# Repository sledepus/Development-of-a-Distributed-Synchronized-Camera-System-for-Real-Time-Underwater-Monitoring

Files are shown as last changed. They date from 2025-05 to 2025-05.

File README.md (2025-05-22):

# Development of a Distributed Synchronized Camera System for Real-Time Underwater Monitoring
<div style="text-align: center;">
    
</div>

This is the Git repository of the bachelor thesis "Development of a Distributed Synchronized Camera System for Real-Time Underwater Monitoring", carried out at the University of Agder by students from the Mechatronics and Electronics engineering programs.

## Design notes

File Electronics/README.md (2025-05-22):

# KiCAD projects for power board and sensor board
BOM for boards are found in their respective folder. PCBs were ordered from JLCPCB, with the power board requiring a specific stackup which can be found in "Specifications for JLCPCB.txt". The sensor board could be ordered with the normal stackup.

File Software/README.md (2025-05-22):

# Overview of dependencies needed
## Sensors:
smbus2 (Python package to interface with I2C via Python)
flask (Python package to run a lightweight HTTP server)
flask_cors (Extension package to flask)

Line 5 in start_monitoring.sh needs to point to correct Python virtual environment

## Sync:
### On Nvidia Jetson:
Jetson.GPIO (Python package to interface with GPIO on Jetson via Python)
Chrony (Lightweight NTP client / server)

Line 5 in start_sync.sh needs to point to correct Python virtual environment

### On Host PC:
aiohttp (Asynchronus HTTP client / server for Python)
Chrony (Lightweight NTP client / server)

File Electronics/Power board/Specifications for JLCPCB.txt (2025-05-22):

4 layer board
1.6mm PCB thickness
ENIG surface finish
Epoxy Filled & Capped vias
JLC04161H-7628 stackup

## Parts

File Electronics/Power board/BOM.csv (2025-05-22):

Reference | Value |  | Footprint | Qty | DNP | Cost | Link | Total cost: | 616.35
C1 | 1nF |  | Capacitor_SMD:C_1808_4520Metric_Pad1.72x2.30mm_HandSolder | 1 |  | 6.33 | https://no.mouser.com/ProductDetail/TDK/C4520X7R3D102K130KA?qs=NRhsANhppD%2FmDDEB06mgKg%3D%3D
C2 | 0.047uF |  | Capacitor_SMD:C_1206_3216Metric_Pad1.33x1.80mm_HandSolder | 1 |  | 5.06 | https://no.mouser.com/ProductDetail/TDK/C3216X7R2A474K160AA?qs=NRhsANhppD%2F0AFSm3iY27A%3D%3D
C3 | 0.047uF |  | Capacitor_SMD:C_1206_3216Metric_Pad1.33x1.80mm_HandSolder | 1 |  | 5.06 | https://no.mouser.com/ProductDetail/TDK/C3216X7R2A474K160AA?qs=NRhsANhppD%2F0AFSm3iY27A%3D%3D
C4 | 0.047uF |  | Capacitor_SMD:C_1206_3216Metric_Pad1.33x1.80mm_HandSolder | 1 |  | 5.06 | https://no.mouser.com/ProductDetail/TDK/C3216X7R2A474K160AA?qs=NRhsANhppD%2F0AFSm3iY27A%3D%3D
C5 | 220uF |  | local symbols:CAPPRD500W65D1250H2700 | 1 |  | 18.63 | https://no.mouser.com/ProductDetail/Panasonic/EEU-FS2A221B?qs=w%2Fv1CP2dgqqAbg7G%252BWfZEw%3D%3D
C6 | 2.2uF |  | Capacitor_SMD:C_1206_3216Metric | 1 |  | 5.06 | https://no.mouser.com/ProductDetail/Samsung-Electro-Mechanics/CL31B225KCHSNNE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
C7 | 2.2uF |  | Capacitor_SMD:C_1206_3216Metric | 1 |  | 5.06 | https://no.mouser.com/ProductDetail/Samsung-Electro-Mechanics/CL31B225KCHSNNE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
C8 | 2.2uF |  | Capacitor_SMD:C_1206_3216Metric | 1 |  | 5.06 | https://no.mouser.com/ProductDetail/Samsung-Electro-Mechanics/CL31B225KCHSNNE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
C9 | 0.1uF |  | Capacitor_SMD:C_0603_1608Metric_Pad1.08x0.95mm_HandSolder | 1 |  | 1.15 | https://no.mouser.com/ProductDetail/Samsung-Electro-Mechanics/CL10B104KC8NNNC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
C10 | 2.2uF |  | Capacitor_SMD:C_1206_3216Metric | 1 |  | 5.06 | https://no.mouser.com/ProductDetail/Samsung-Electro-Mechanics/CL31B225KCHSNNE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
C11 | 1uF |  | Capacitor_SMD:C_0603_1608Metric_Pad1.08x0.95mm_HandSolder | 1 |  | 3.11 | https://no.mouser.com/ProductDetail/TDK/C1608X7R2A105K080AC?qs=efUn273yAhc5BfjaNflQJg%3D%3D
C12 | 2.2uF |  | Capacitor_SMD:C_1206_3216Metric | 1 |  | 5.06 | https://no.mouser.com/ProductDetail/Samsung-Electro-Mechanics/CL31B225KCHSNNE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
C13 | 2.2uF |  | Capacitor_SMD:C_1206_3216Metric | 1 |  | 5.06 | https://no.mouser.com/ProductDetail/Samsung-Electro-Mechanics/CL31B225KCHSNNE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
C14 | 2.2uF |  | Capacitor_SMD:C_1206_3216Metric | 1 |  | 5.06 | https://no.mouser.com/ProductDetail/Samsung-Electro-Mechanics/CL31B225KCHSNNE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
C15 | 22nF |  | Capacitor_SMD:C_0603_1608Metric_Pad1.08x0.95mm_HandSolder | 1 |  | 1.15 | https://no.mouser.com/ProductDetail/TDK/C1608X7R1H223K080AA?qs=NRhsANhppD%2FQDsEEQkak2g%3D%3D
C16 | 0.18uF |  | Capacitor_SMD:C_0603_1608Metric_Pad1.08x0.95mm_HandSolder | 1 |  | 2.07 | https://no.mouser.com/ProductDetail/Murata-Electronics/GRM188R71E184JA88D?qs=4W3PNmGdEWESKFPR14%2FptQ%3D%3D
C17 | 20SVPA10M |  | local symbols:16SVF82M | 1 |  | 10.12 | https://no.mouser.com/ProductDetail/Panasonic/20SVPA10M?qs=kmv%2FWw32SUMFO%252BR%252BBoc1uQ%3D%3D
C18 | 20SVPA10M |  | local symbols:16SVF82M | 1 |  | 10.12 | https://no.mouser.com/ProductDetail/Panasonic/20SVPA10M?qs=kmv%2FWw32SUMFO%252BR%252BBoc1uQ%3D%3D
C19 | 4.7uF |  | Capacitor_SMD:C_1206_3216Metric_Pad1.33x1.80mm_HandSolder | 1 |  | 3.34 | https://no.mouser.com/ProductDetail/TDK/C3216X7R1E475K160AC?qs=NRhsANhppD%252B1ueqJBZSgVQ%3D%3D
C20 | C |  | Capacitor_SMD:C_0603_1608Metric_Pad1.08x0.95mm_HandSolder | 1 |  | DNP | DNP
C21 | 0.1uF |  | Capacitor_SMD:C_1206_3216Metric_Pad1.33x1.80mm_HandSolder | 1 |  | 2.76 | https://no.mouser.com/ProductDetail/TDK/C3216X7R2A104M160AA?qs=NRhsANhppD9n088ccj0Rog%3D%3D
D1 | SMAJ60A |  | Diode_SMD:D_SMA | 1 |  | 3.11 | https://no.mouser.com/ProductDetail/Littelfuse/SMAJ60A?qs=JJML70Qc14uXU90ZhvFagg%3D%3D
J1 | 2250504-1 |  | local symbols:22505041 | 1 |  | 103.33 | https://no.mouser.com/ProductDetail/TRP-Connector-Bel/2250504-1?qs=BZBei1rCqCBflgaPUpS30g%3D%3D
J2 | SS-60000-008 |  | local symbols:BEL_SS-60000-008 | 1 |  | 42.71 | https://no.mouser.com/ProductDetail/Stewart-Connector-Bel/SS-60000-008?qs=FESYatJ8odLtCYolbGascQ%3D%3D
J3 | Conn_02x01 |  | Connector_PinHeader_2.54mm:PinHeader_2x01_P2.54mm_Vertical | 1 |  | DNP | DNP
J4 | Conn_02x01 |  | Connector_PinHeader_2.54mm:PinHeader_2x01_P2.54mm_Vertical | 1 |  | DNP | DNP
J5 | 1935187 |  | local symbols:1935187 | 1 |  | 11.16 | https://no.mouser.com/ProductDetail/Phoenix-Contact/1935187?qs=W3wJikR1%252BS5tIYApIw6HoQ%3D%3D
L1 | 10uH |  | local symbols:WE-XHMI_1090 | 1 |  | 63.77 | https://no.mouser.com/ProductDetail/Wurth-Elektronik/74439369100?qs=rQFj71Wb1eU71nvM%252BwSuXg%3D%3D
Q1 | PSMN040-100MSE |  | Package_TO_SOT_SMD:LFPAK33 | 1 |  | 12.95 | https://no.mouser.com/ProductDetail/Nexperia/PSMN040-100MSEX?qs=5XOdhvmYM0P4Ftmbr2cr4A%3D%3D
Q2 | PSMN040-100MSE |  | Package_TO_SOT_SMD:LFPAK33 | 1 |  | 12.95 | https://no.mouser.com/ProductDetail/Nexperia/PSMN040-100MSEX?qs=5XOdhvmYM0P4Ftmbr2cr4A%3D%3D
Q3 | PSMN040-100MSE |  | Package_TO_SOT_SMD:LFPAK33 | 1 |  | 12.95 | https://no.mouser.com/ProductDetail/Nexperia/PSMN040-100MSEX?qs=5XOdhvmYM0P4Ftmbr2cr4A%3D%3D
Q4 | PSMN040-100MSE |  | Package_TO_SOT_SMD:LFPAK33 | 1 |  | 12.95 | https://no.mouser.com/ProductDetail/Nexperia/PSMN040-100MSEX?qs=5XOdhvmYM0P4Ftmbr2cr4A%3D%3D
Q5 | PSMN040-100MSE |  | Package_TO_SOT_SMD:LFPAK33 | 1 |  | 12.95 | https://no.mouser.com/ProductDetail/Nexperia/PSMN040-100MSEX?qs=5XOdhvmYM0P4Ftmbr2cr4A%3D%3D
Q6 | PSMN040-100MSE |  | Package_TO_SOT_SMD:LFPAK33 | 1 |  | 12.95 | https://no.mouser.com/ProductDetail/Nexperia/PSMN040-100MSEX?qs=5XOdhvmYM0P4Ftmbr2cr4A%3D%3D
Q7 | PSMN040-100MSE |  | Package_TO_SOT_SMD:LFPAK33 | 1 |  | 12.95 | https://no.mouser.com/ProductDetail/Nexperia/PSMN040-100MSEX?qs=5XOdhvmYM0P4Ftmbr2cr4A%3D%3D
Q8 | PSMN040-100MSE |  | Package_TO_SOT_SMD:LFPAK33 | 1 |  | 12.95 | https://no.mouser.com/ProductDetail/Nexperia/PSMN040-100MSEX?qs=5XOdhvmYM0P4Ftmbr2cr4A%3D%3D
Q9 | PSMN040-100MSE |  | Package_TO_SOT_SMD:LFPAK33 | 1 |  | 12.95 | https://no.mouser.com/ProductDetail/Nexperia/PSMN040-100MSEX?qs=5XOdhvmYM0P4Ftmbr2cr4A%3D%3D
R1 | 75 |  | Resistor_SMD:R_1206_3216Metric_Pad1.30x1.75mm_HandSolder | 1 |  | 1.15 | https://no.mouser.com/ProductDetail/YAGEO/RT1206DRE0775RL?qs=sGAEpiMZZMvdGkrng054t98Xz4DA4UW4Ozg3T4IT1xw%3D
R2 | 75 |  | Resistor_SMD:R_1206_3216Metric_Pad1.30x1.75mm_HandSolder | 1 |  | 1.15 | https://no.mouser.com/ProductDetail/YAGEO/RT1206DRE0775RL?qs=sGAEpiMZZMvdGkrng054t98Xz4DA4UW4Ozg3T4IT1xw%3D
R3 | 75 |  | Resistor_SMD:R_1206_3216Metric_Pad1.30x1.75mm_HandSolder | 1 |  | 1.15 | https://no.mouser.com/ProductDetail/YAGEO/RT1206DRE0775RL?qs=sGAEpiMZZMvdGkrng054t98Xz4DA4UW4Ozg3T4IT1xw%3D
R4 | 75 |  | Resistor_SMD:R_1206_3216Metric_Pad1.30x1.75mm_HandSolder | 1 |  | 1.15 | https://no.mouser.com/ProductDetail/YAGEO/RT1206DRE0775RL?qs=sGAEpiMZZMvdGkrng054t98Xz4DA4UW4Ozg3T4IT1xw%3D
R5 | 49.9 |  | Resistor_SMD:R_0603_1608Metric_Pad0.98x0.95mm_HandSolder | 1 |  | 1.5 | https://no.mouser.com/ProductDetail/Vishay-Dale/RCS060349R9FKEA
R6 | 118 |  | Resistor_SMD:R_0603_1608Metric_Pad0.98x0.95mm_HandSolder | 1 |  | 1.22 | https://no.mouser.com/ProductDetail/KOA-Speer/RK73H1JTTD1180F?qs=beCmh%2FXShNfPnDZ%2FNfW%252BWA%3D%3D
R7 | 0 |  | Resistor_SMD:R_1206_3216Metric_Pad1.30x1.75mm_HandSolder | 1 |  | 1.15 | https://no.mouser.com/ProductDetail/Vishay-Dale/CRCW12060000Z0EC
R8 | 3.3k |  | Resistor_SMD:R_0603_1608Metric_Pad0.98x0.95mm_HandSolder | 1 |  | 1.15 | https://no.mouser.com/ProductDetail/YAGEO/AC0603JR-073K3L?qs=sGAEpiMZZMvdGkrng054t7zOzNqIRvGcrCxgTvkGHR4%3D
R9 | 100k |  | Resistor_SMD:R_0603_1608Metric_Pad0.98x0.95mm_HandSolder | 1 |  | 1.15 | https://no.mouser.com/ProductDetail/YAGEO/AT0603FRE07100KL
R10 | 2.21k |  | Resistor_SMD:R_0603_1608Metric_Pad0.98x0.95mm_HandSolder | 1 |  | 1.15 | https://no.mouser.com/ProductDetail/Panasonic/ERJ-3EKF2211V?qs=sGAEpiMZZMvdGkrng054t8ugkoYZivkgwRdtRslwd94%3D
R11 | 2.2 |  | Resistor_SMD:R_0603_1608Metric_Pad0.98x0.95mm_HandSolder | 1 |  | 2.42 | https://no.mouser.com/ProductDetail/Vishay-Dale/RCS06032R20FKEA
R12 | 348 |  | Resistor_SMD:R_0603_1608Metric_Pad0.98x0.95mm_HandSolder | 1 |  | 2.42 | https://no.mouser.com/ProductDetail/Panasonic/ERJ-H3EF3480V
R13 | 8.2k |  | Resistor_SMD:R_0603_1608Metric_Pad0.98x0.95mm_HandSolder | 1 |  | 1.61 | https://no.mouser.com/ProductDetail/Vishay-Dale/RCS06038K20FKEA
R14 | 100k |  | Resistor_SMD:R_0603_1608Metric_Pad0.98x0.95mm_HandSolder | 1 |  | 1.15 | https://no.mouser.com/ProductDetail/YAGEO/AT0603FRE07100KL
R15 | 2.2 |  | Resistor_SMD:R_0603_1608Metric_Pad0.98x0.95mm_HandSolder | 1 |  | 2.42 | https://no.mouser.com/ProductDetail/Vishay-Dale/RCS06032R20FKEA
R16 | R |  | Resistor_SMD:R_0603_1608Metric_Pad0.98x0.95mm_HandSolder | 1 |  | DNP | DNP
U1 | LT4321IUF |  | Package_DFN_QFN:QFN-16-1EP_4x4mm_P0.65mm_EP2.15x2.15mm | 1 |  | 46.39 | https://www.digikey.no/no/products/detail/analog-devices-inc/LT4321IUF-PBF/4431235
U2 | LT4293IMS-PBF |  | footprints:05-08-1661_ADI | 1 |  | 58.08 | https://no.mouser.com/ProductDetail/Analog-Devices/LT4293IMSPBF?qs=PzGy0jfpSMs1qV0%2FehZ1Mw%3D%3D
U3 | MIC28516T-E/PHA |  | footprints:VQFN32_6X6_3EP_PHA_MCH | 1 |  | 39.93 | https://no.mouser.com/ProductDetail/Microchip-Technology/MIC28516T-E-PHA?qs=y6ZabgHbY%252By6jC%2FkhCS6gQ%3D%3D
 | Komponenter til 1 kort | 616.35
 | Bestilling av 5 kort (uten stencil) | 832.44
 | eller
 | Bestilling av 5 kort (med stencil) | 1172.45
 | Totalt pr kort (uten stencil) | 782.838
 | Totalt pr kort (med stencil) | 850.84

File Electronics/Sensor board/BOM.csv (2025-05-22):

Reference | Value | Datasheet | Footprint | Qty | Part number
C1, C3 | 100nF | ~ | Capacitor_SMD:C_1206_3216Metric | 1 | VJ1206Y104KXQCW1BC
C2 | 1uF | ~ | Capacitor_SMD:C_1206_3216Metric | 2 | 1206ZC105KAT2A
C3 | 10uF | ~ | Capacitor_SMD:C_1206_3216Metric | 1 | CL31B106KPHNNNE
IC1 | ADXL345BCCZ | http://www.st.com/resource/en/datasheet/lsm6ds3tr-c.pdf | KiCad:LSM6DS3USTR | 1 | ADXL345BCCZ
J1,J2 | 4328 |  | Library:ADAFRUIT_4328 | 2 | 485-4328
R1,R2,R3,R4 | 2.2k | ~ | Resistor_SMD:R_1206_3216Metric | 4 | CRCW12062K20FKEAC
U1 | SHTC3 | https://www.sensirion.com/fileadmin/user_upload/customers/sensirion/Dokumente/0_Datasheets/Humidity/Sensirion_Humidity_Sensors_SHTC3_Datasheet.pdf | Sensor_Humidity:Sensirion_DFN-4-1EP_2x2mm_P1mm_EP0.7x1.6mm | 1 | SHTC3

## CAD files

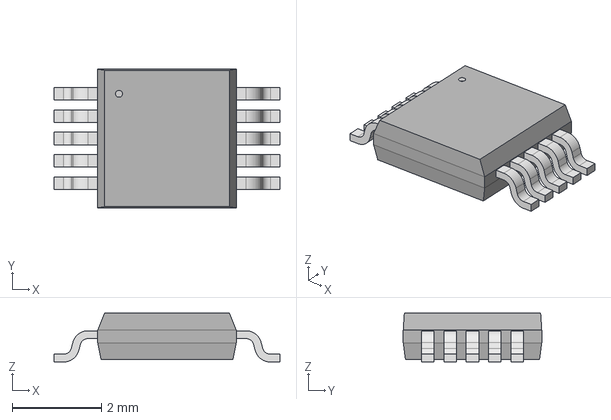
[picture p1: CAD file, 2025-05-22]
Electronics/Power board/local symbols/KiCADv6/05-08-1661_ADI.step
5.05 x 3.10 x 1.09 mm

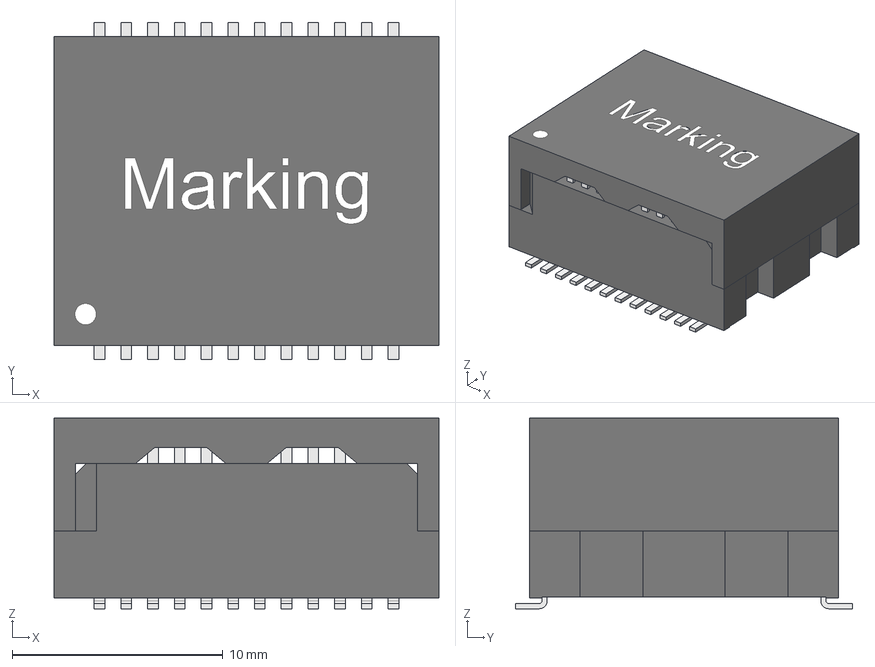
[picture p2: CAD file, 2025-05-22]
Electronics/Power board/local symbols/WE-LAN_7490220122.step
18.3 x 16.0 x 9.05 mm
Housing
Cover
Pins x 24

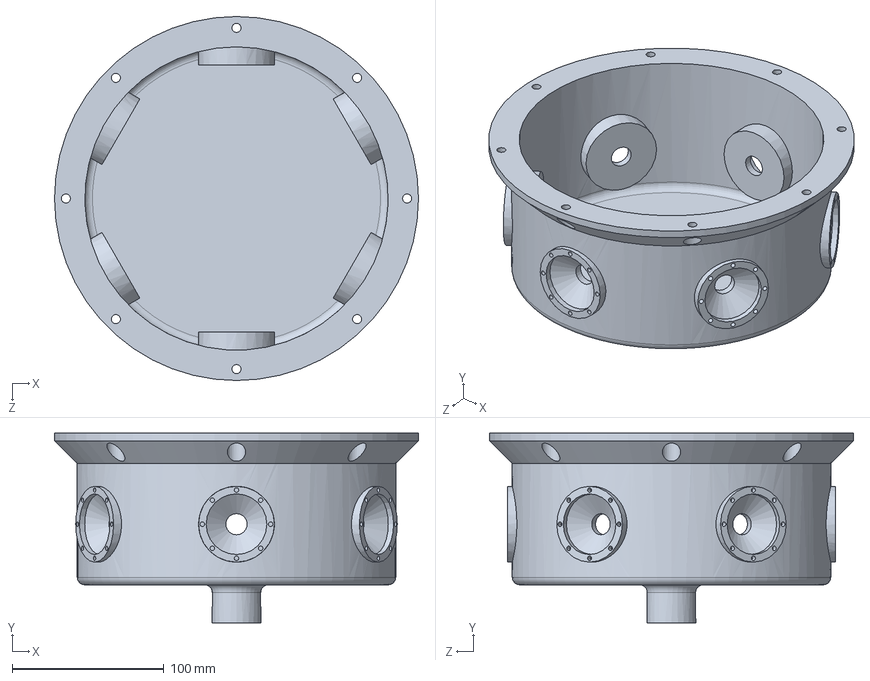
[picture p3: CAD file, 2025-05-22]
Mechanical Assembly - CAD/Final updated design/Top_node.SLDPRT
240.0 x 125.0 x 240.0 mm

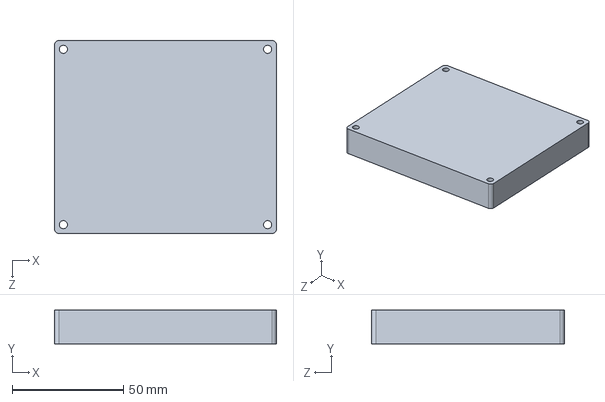
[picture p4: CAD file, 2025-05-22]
Mechanical Assembly - CAD/Hexadome Prototype/Jetson_Dummy_Thermals.SLDPRT
100.0 x 15.3 x 87.0 mm

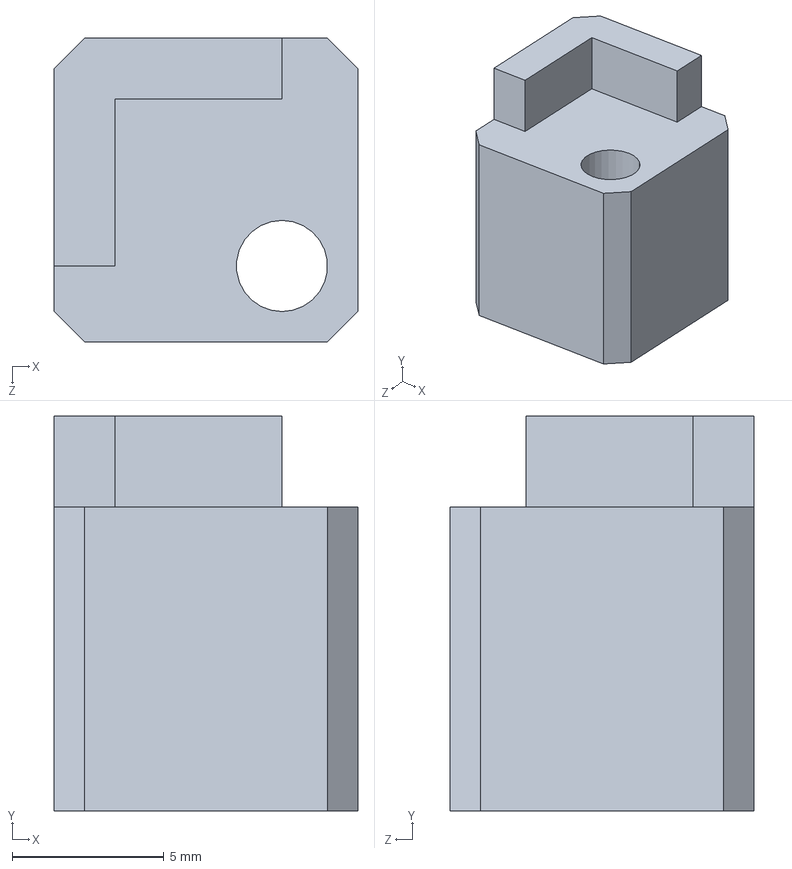
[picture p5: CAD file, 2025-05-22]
Mechanical Assembly - CAD/POE Board/POE_PCB_bracket.SLDPRT
10.0 x 13.0 x 10.0 mm

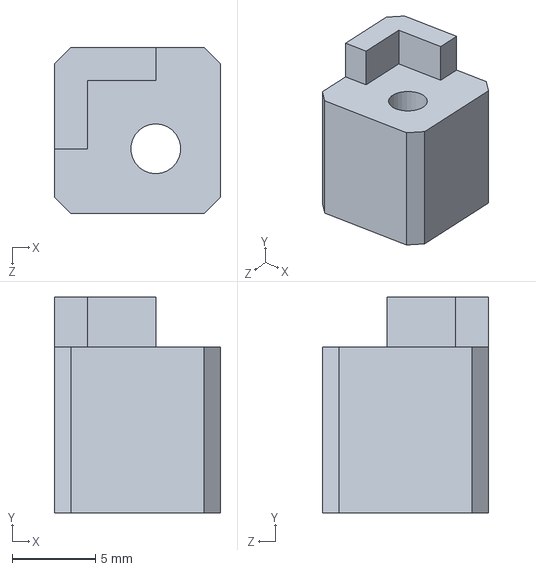
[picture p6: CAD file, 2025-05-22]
Mechanical Assembly - CAD/Sensor Board/Small_Sensor_PCB_bracket.SLDPRT
10.0 x 13.0 x 10.0 mm

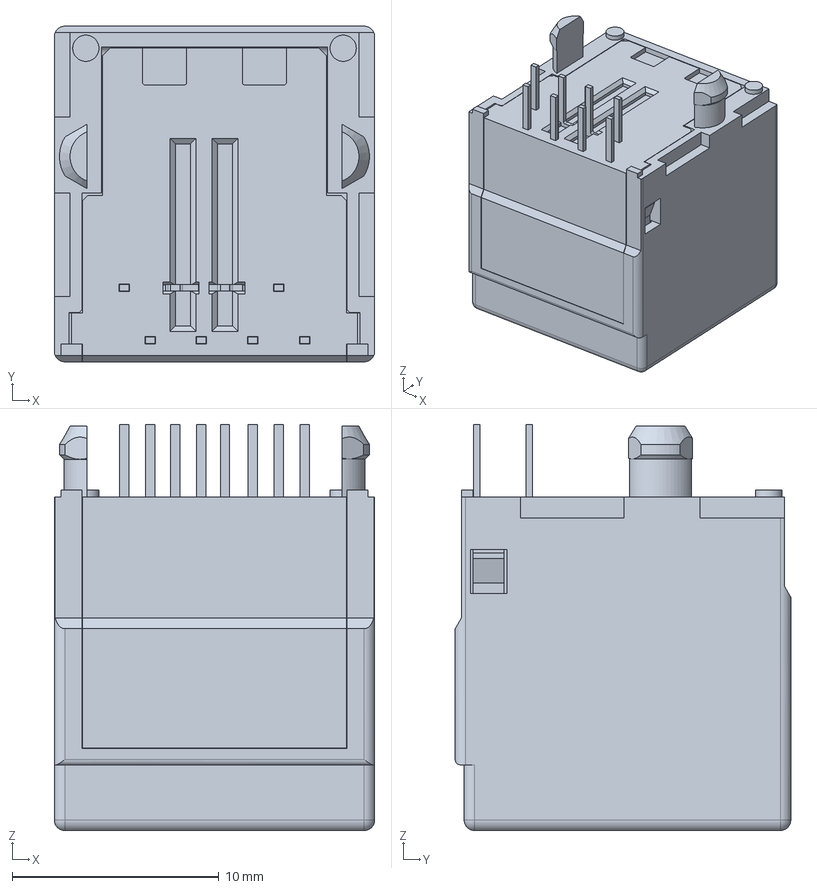
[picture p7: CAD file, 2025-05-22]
Electronics/Power board/local symbols/BEL_SS-7188VS-A-NF-50.stp
15.5 x 16.2 x 19.6 mm
SS-7188V-A-NF-50_PART1
SS-7188V-A-NF-50_PART2
SS-7188V-A-NF-50_PART3
SS-7188V-A-NF-50_PART4
SS-7188V-A-NF-50_PART5

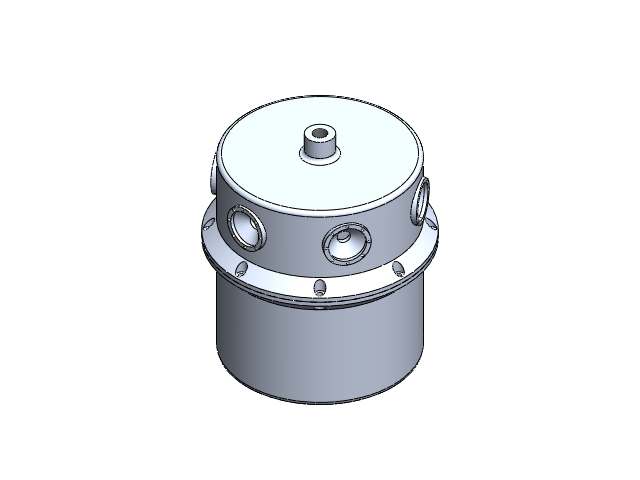
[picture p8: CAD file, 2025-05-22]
Mechanical Assembly - CAD/Final updated design/Pressure_asm.SLDASM
Bottom_node
Top_node

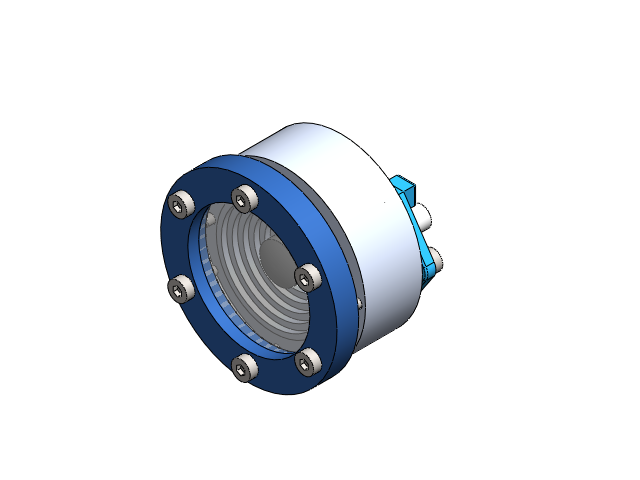
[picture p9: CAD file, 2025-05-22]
Mechanical Assembly - CAD/Hexadome Prototype/Camera_asm_45mm.SLDASM
Lens_glass_45
Lens_cover_simple
m3_screw x 6
m3x20_screw x 2
e_con_camera_body
e_con_camera_PCB x 2
e_con_camera_lens
Standoff x 4
Coax_connector
Camera_bracket_v3_45mm
Camera_lock_v2

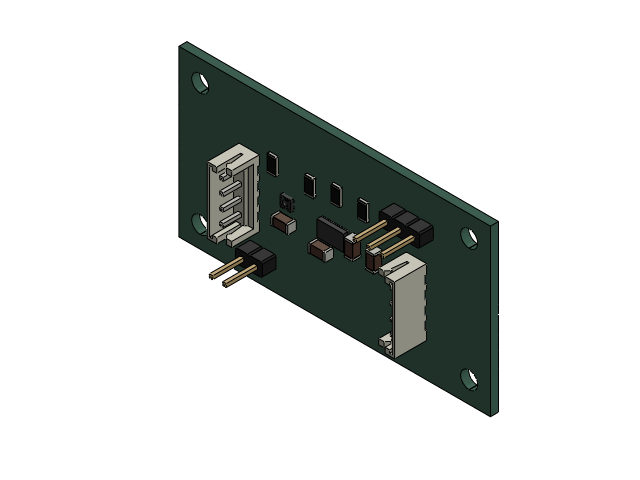
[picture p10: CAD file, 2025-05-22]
Mechanical Assembly - CAD/Sensor Board/Sensor_PCB.SLDASM
PinHeader_1x02_P2.54mm_Vertical.step
SHTC3.step
ADXL345BCCZ.step
PinHeader_1x03_P2.54mm_Vertical.step
C_1206_3216Metric.step x 4
JST_EH_B4B-EH-A_1x04_P2.50mm_Vertical.step x 2
R_1206_3216Metric.step x 4
Sensor_PCB.step

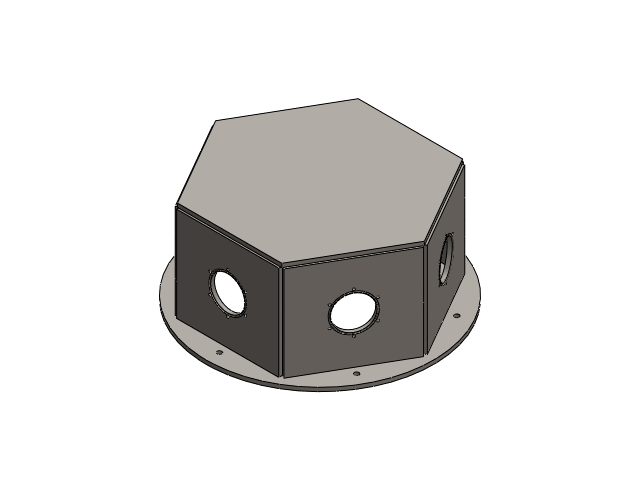
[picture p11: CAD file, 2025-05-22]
Mechanical Assembly - CAD/Hexadome Prototype/Wide_top_asm.SLDASM
Wide_lock
Wide_flange
Wide_top_wall x 6

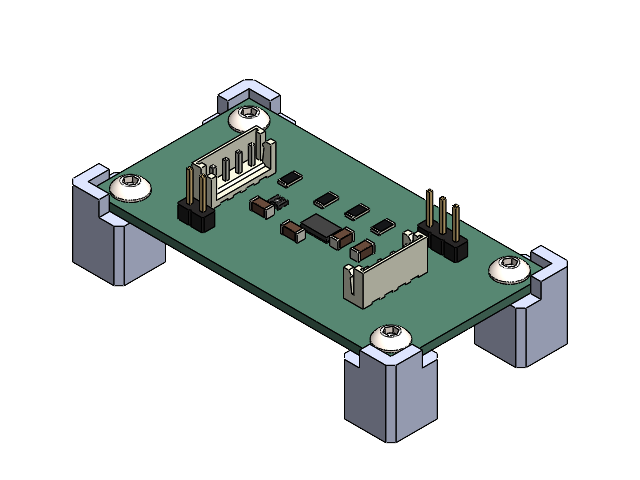
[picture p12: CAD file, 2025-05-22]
Mechanical Assembly - CAD/Final updated design/Sensor_PCB_asm.SLDASM
Small_Sensor_PCB_bracket x 4
PinHeader_1x02_P2.54mm_Vertical.step
SHTC3.step
ADXL345BCCZ.step
PinHeader_1x03_P2.54mm_Vertical.step
C_1206_3216Metric.step x 4
JST_EH_B4B-EH-A_1x04_P2.50mm_Vertical.step x 2
R_1206_3216Metric.step x 4
Sensor_PCB.step
socket button head screw_iso x 4

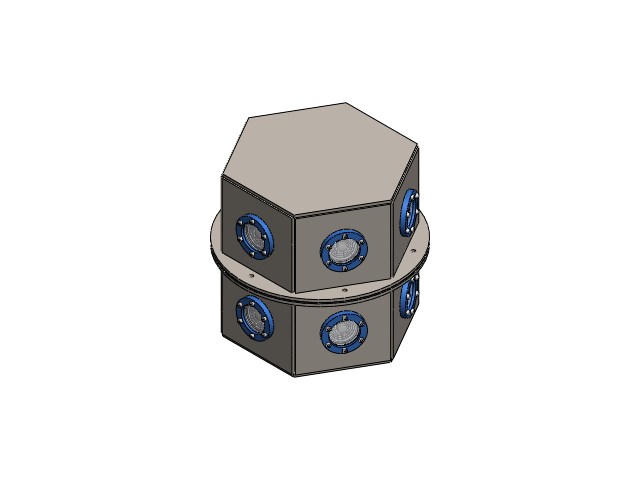
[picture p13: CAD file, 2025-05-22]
Mechanical Assembly - CAD/Hexadome Prototype/Stereo_node.SLDASM
Wide_lock x 2
Wide_flange x 2
Wide_top_wall x 12
Lens_glass_45 x 12
Lens_cover_simple x 12
m3_screw x 72
m3x20_screw x 24
e_con_camera_body x 12
e_con_camera_PCB x 24
e_con_camera_lens x 12
Standoff x 48
Coax_connector x 12
Camera_bracket_v3_45mm x 12
Camera_lock_v2 x 12
Wide_Gasket

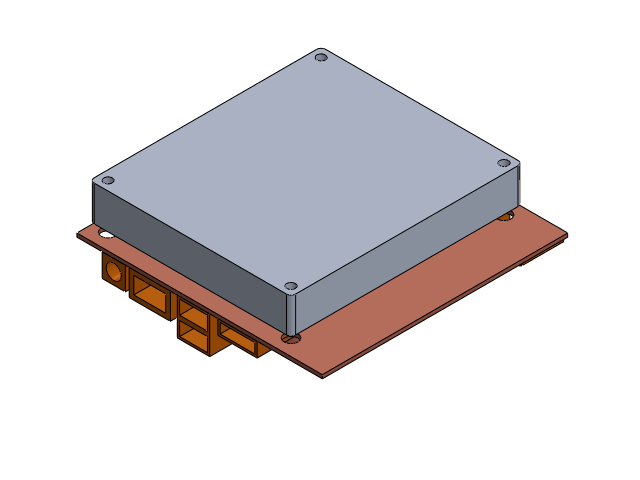
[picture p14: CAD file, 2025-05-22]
Mechanical Assembly - CAD/Hexadome Prototype/Jetson_Dummy_asm.SLDASM
Jetson_Dummy_PCB
Jetson_Dummy_Thermals
Jetson_Dummy_Serial_board

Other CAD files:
Mechanical Assembly - CAD/Hexadome Prototype/Lens_asm.SLDASM
Mechanical Assembly - CAD/Hexadome Prototype/Wide_node_case_asm.SLDASM
Mechanical Assembly - CAD/Hexadome Prototype/Wide_bottom_asm.SLDASM
Electronics/Power board/local symbols/05-08-1661_ADI.step
Electronics/Power board/local symbols/1711042.stp
Electronics/Power board/local symbols/1935187.stp
Electronics/Power board/local symbols/20SVPA10M.stp
Electronics/Power board/local symbols/2250504-1.stp
Electronics/Power board/local symbols/Download_STP_WE-XHMI-1090 (rev1).stp
Electronics/Power board/local symbols/EEU-FS2A221B.stp
Electronics/Power board/local symbols/EEV-FK2A221M.stp
Electronics/Power board/local symbols/LT4293IMS_PBF.step
Electronics/Power board/local symbols/MIC28516T-E_PHA.stp
Electronics/Power board/local symbols/SS-60000-008.step
Electronics/Power board/local symbols/SS-60300-080.step
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

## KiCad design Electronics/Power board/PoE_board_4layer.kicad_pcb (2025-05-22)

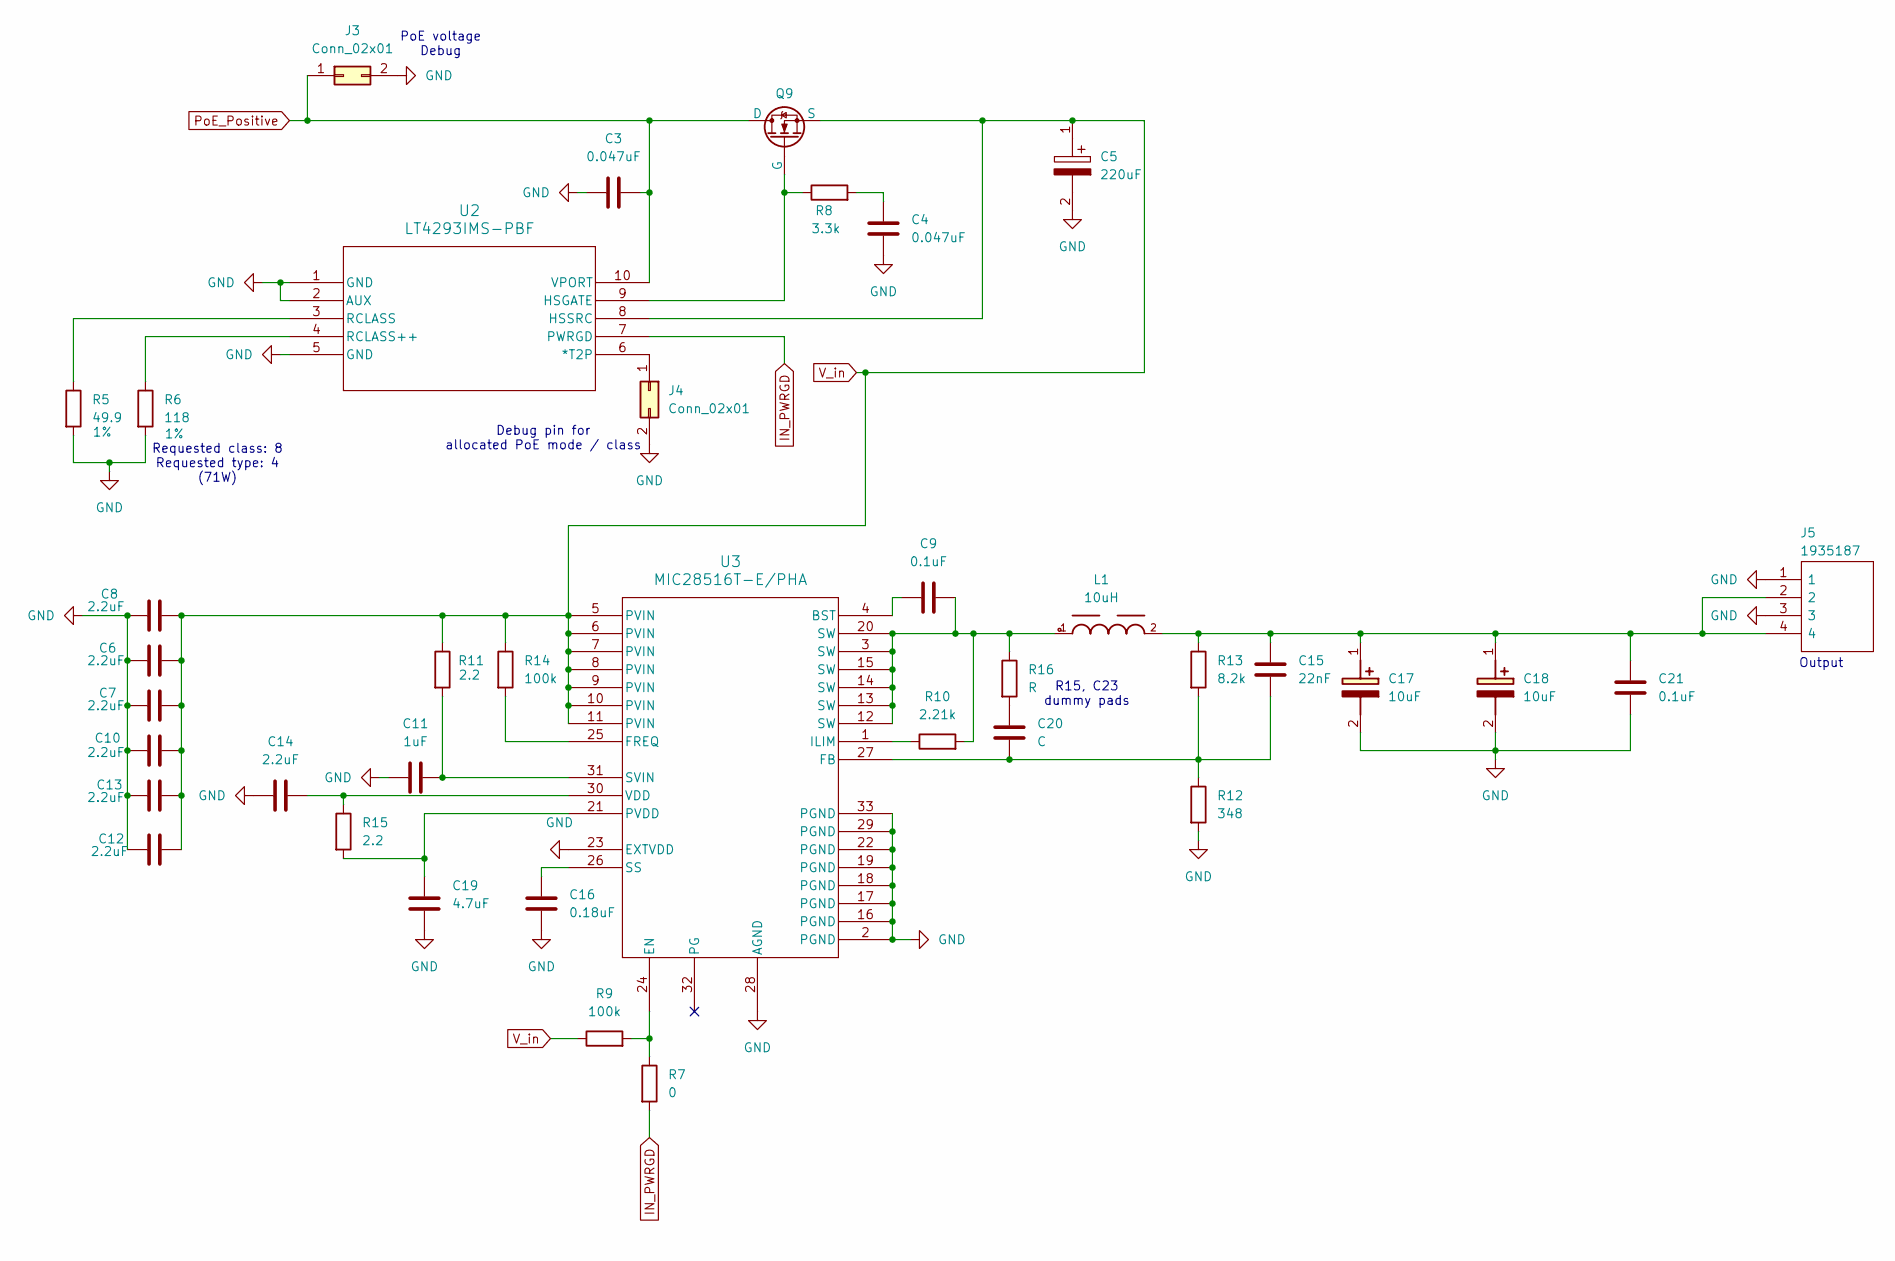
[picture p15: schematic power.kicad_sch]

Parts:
C3, C4: 0.047uF; C_1206_3216Metric_Pad1.33x1.80mm_HandSolder
C5: 220uF; CAPPRD500W65D1250H2700; Mouser Part Number 667-EEU-FS2A221B
C6, C7, C8, C10, C12, C13, C14: 2.2uF; C_1206_3216Metric
C9: 0.1uF; C_0603_1608Metric_Pad1.08x0.95mm_HandSolder
C11: 1uF; C_0603_1608Metric_Pad1.08x0.95mm_HandSolder
C15: 22nF; C_0603_1608Metric_Pad1.08x0.95mm_HandSolder
C16: 0.18uF; C_0603_1608Metric_Pad1.08x0.95mm_HandSolder
C17, C18: 10uF; 16SVF82M; Mouser Part Number 667-20SVPA10M
C19: 4.7uF; C_1206_3216Metric_Pad1.33x1.80mm_HandSolder
C20: C; C_1206_3216Metric_Pad1.33x1.80mm_HandSolder
C21: 0.1uF; C_1206_3216Metric_Pad1.33x1.80mm_HandSolder
J3, J4: Conn_02x01; PinHeader_2x01_P2.54mm_Vertical
J5: 1935187; Mouser Part Number 651-1935187
L1: 10uH; WE-XHMI_1090
Q9: PSMN040-100MSE; LFPAK33
R5: 49.9; R_0603_1608Metric_Pad0.98x0.95mm_HandSolder; Tolerance 1%
R6: 118; R_0603_1608Metric_Pad0.98x0.95mm_HandSolder; Tolerance 1%
R7: 0; R_1206_3216Metric_Pad1.30x1.75mm_HandSolder
R8: 3.3k; R_0603_1608Metric_Pad0.98x0.95mm_HandSolder
R9, R14: 100k; R_0603_1608Metric_Pad0.98x0.95mm_HandSolder
R10: 2.21k; R_0603_1608Metric_Pad0.98x0.95mm_HandSolder
R11, R15: 2.2; R_0603_1608Metric_Pad0.98x0.95mm_HandSolder
R12: 348; R_0603_1608Metric_Pad0.98x0.95mm_HandSolder
R13: 8.2k; R_0603_1608Metric_Pad0.98x0.95mm_HandSolder
R16: R; R_1206_3216Metric_Pad1.30x1.75mm_HandSolder
U2: LT4293IMS-PBF; 05-08-1661_ADI
U3: MIC28516T-E/PHA; VQFN32_6X6_3EP_PHA_MCH

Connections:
GND: C3.1, C4.2, C5.2, C6.1, C7.1, C8.1, C10.1, C11.2, C12.1, C13.1, C14.1, C16.2, C17.2 (-), C18.2 (-), C19.2, C21.2, J3.2, J4.2, J5.1, J5.3, R5.2, R6.2, R12.2, U2.1 (GND), U2.2 (AUX), U2.5 (GND), U3.2 (PGND), U3.16 (PGND), U3.17 (PGND), U3.18 (PGND), U3.19 (PGND), U3.22 (PGND), U3.23 (EXTVDD), U3.28 (AGND), U3.29 (PGND), U3.33 (PGND); also elsewhere on the board
IN_PWRGD: R7.2, U2.7 (PWRGD); also elsewhere on the board
unnamed: C4.1, R8.2
unnamed: C9.2, L1.1, R10.2, R16.1, U3.3 (SW), U3.12 (SW), U3.13 (SW), U3.14 (SW), U3.15 (SW), U3.20 (SW)
unnamed: C15.1, C17.1 (+), C18.1 (+), C21.1, J5.2, J5.4, L1.2, R13.1
unnamed: C20.1, R16.2
unnamed: J4.1, U2.6 (*T2P)
unnamed: Q9.4 (G), R8.1, U2.9 (HSGATE)
unnamed: R5.1, U2.3 (RCLASS)
unnamed: R6.1, U2.4 (RCLASS++)
unnamed: C9.1, U3.4 (BST)
unnamed: R7.1, R9.2, U3.24 (EN)
unnamed: C15.2, C20.2, R12.1, R13.2, U3.27 (FB)
unnamed: R14.2, U3.25 (FREQ)
unnamed: R10.1, U3.1 (ILIM)
unnamed: C19.1, R15.2, U3.21 (PVDD)
unnamed: C16.1, U3.26 (SS)
unnamed: C11.1, R11.2, U3.31 (SVIN)
unnamed: C14.2, R15.1, U3.30 (VDD)
PoE_Positive: C3.2, J3.1, Q9.5 (D), U2.10 (VPORT); also elsewhere on the board
V_in: C5.1, C6.2, C7.2, C8.2, C10.2, C12.2, C13.2, Q9.1 (S), Q9.2 (S), Q9.3 (S), R9.1, R11.1, R14.1, U2.8 (HSSRC), U3.5 (PVIN), U3.6 (PVIN), U3.7 (PVIN), U3.8 (PVIN), U3.9 (PVIN), U3.10 (PVIN), U3.11 (PVIN)

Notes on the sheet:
Requested class: 8 Requested type: 4 (71W)
PoE voltage Debug
Output
Debug pin for allocated PoE mode / class
R15, C23 dummy pads

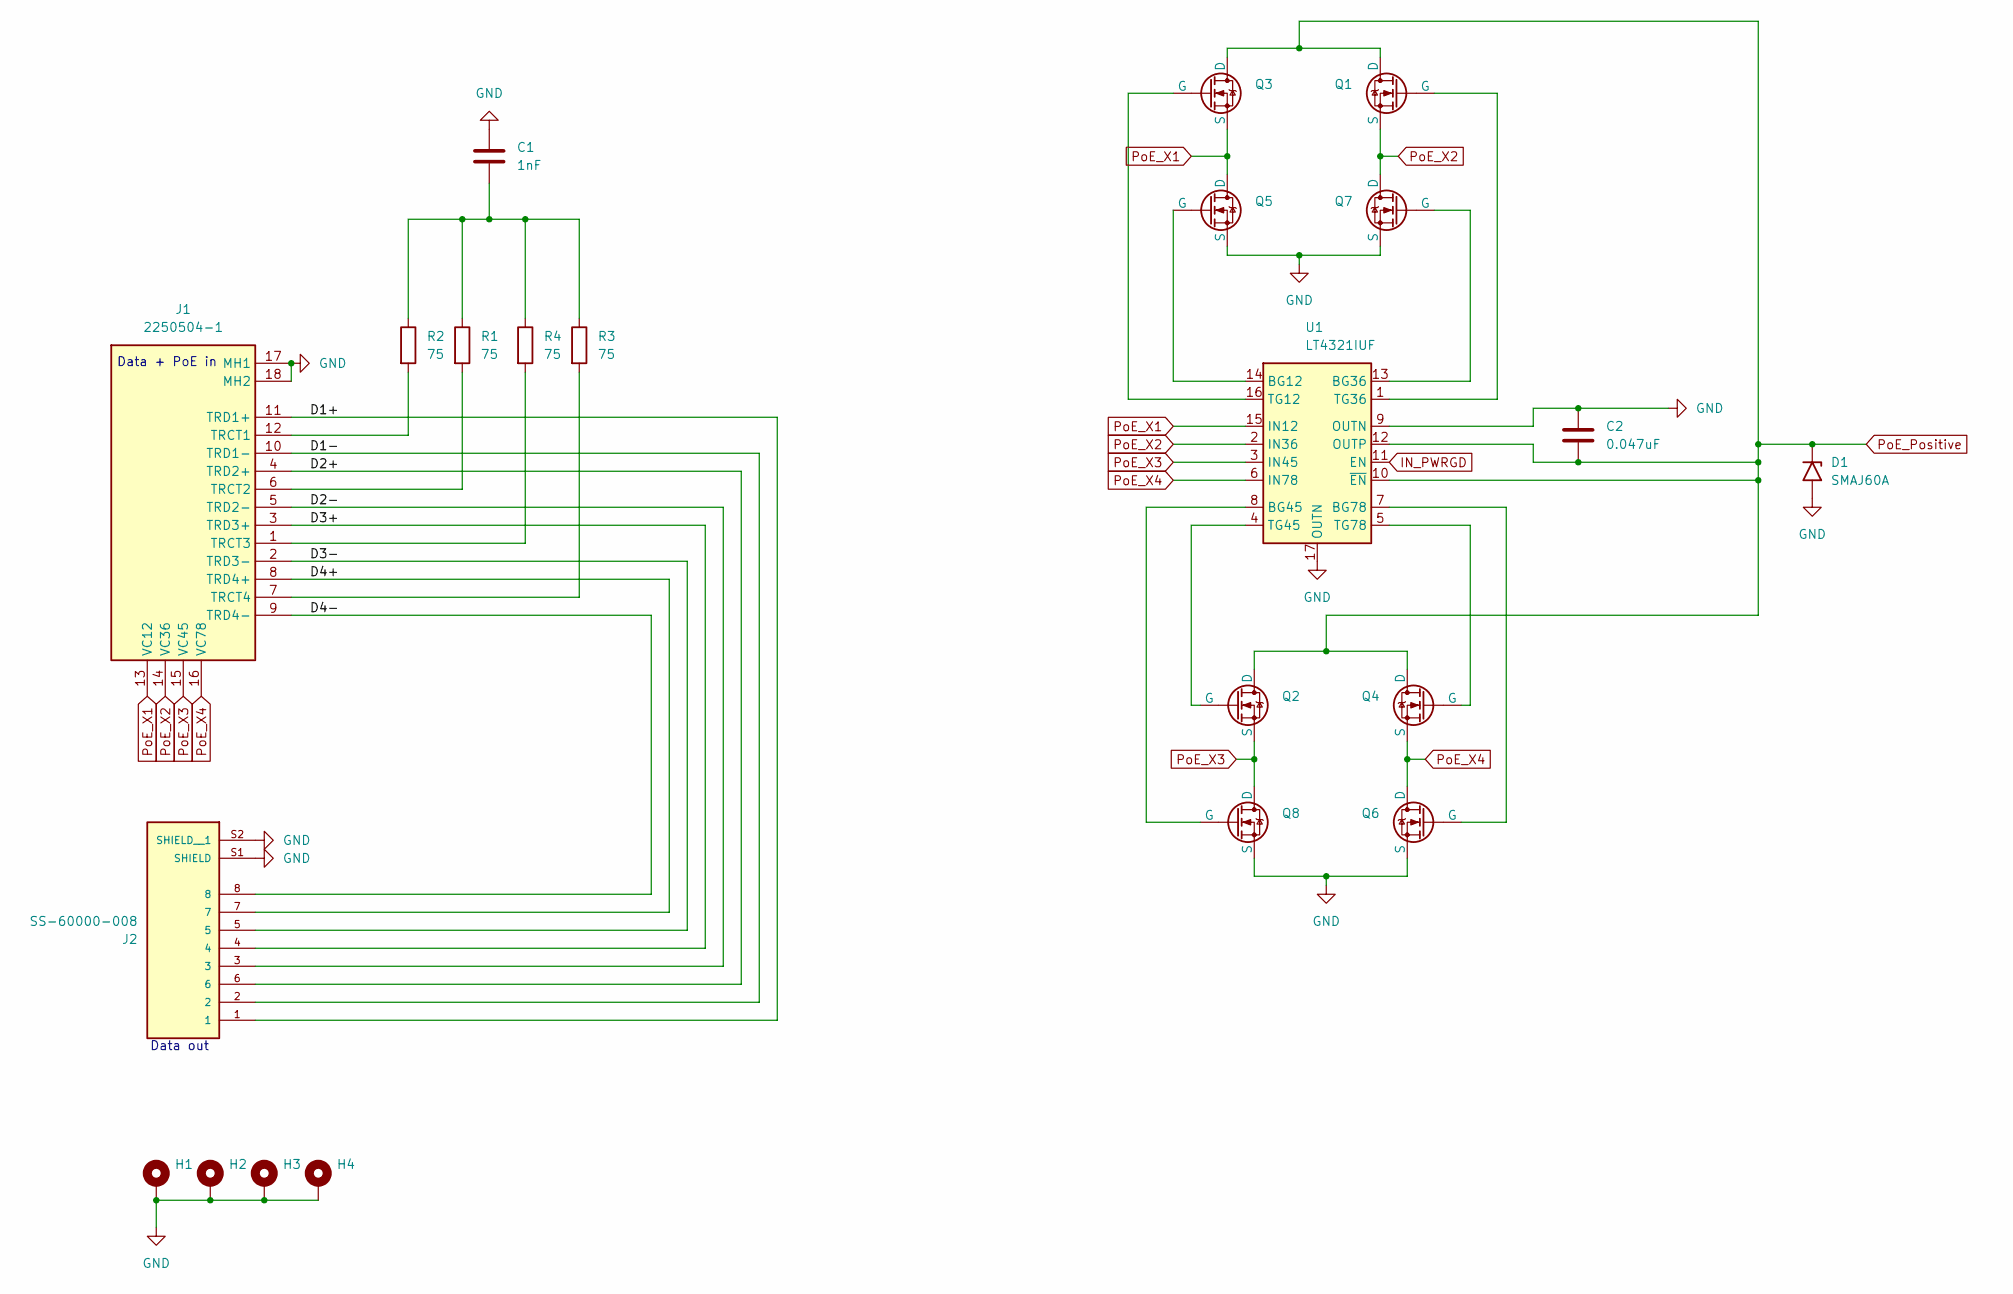
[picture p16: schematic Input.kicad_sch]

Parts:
C1: 1nF; C_1808_4520Metric_Pad1.72x2.30mm_HandSolder
C2: 0.047uF; C_1206_3216Metric_Pad1.33x1.80mm_HandSolder
D1: SMAJ60A; D_SMA
H1, H2, H3, H4: MountingHole_Pad; MountingHole_3.2mm_M3_Pad
J1: 2250504-1; 22505041; Mouser Part Number 530-2250504-1
J2: SS-60000-008; BEL_SS-60000-008; PARTREV C6
Q1, Q2, Q3, Q4, Q5, Q6, Q7, Q8: PSMN040-100MSE; LFPAK33
R1, R2, R3, R4: 75; R_1206_3216Metric_Pad1.30x1.75mm_HandSolder
U1: LT4321IUF; QFN-16-1EP_4x4mm_P0.65mm_EP2.15x2.15mm

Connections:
/Input/D1+: J1.11 (TRD1+), J2.1
/Input/D1-: J1.10 (TRD1-), J2.2
/Input/D2+: J1.4 (TRD2+), J2.6
/Input/D2-: J1.5 (TRD2-), J2.3
/Input/D3+: J1.3 (TRD3+), J2.4
/Input/D3-: J1.2 (TRD3-), J2.5
/Input/D4+: J1.8 (TRD4+), J2.7
/Input/D4-: J1.9 (TRD4-), J2.8
GND: C1.1, C2.1, D1.2 (A2), H1.1, H2.1, H3.1, H4.1, J1.17 (MH1), J1.18 (MH2), J2.S1 (SHIELD), J2.S2 (SHIELD__1), Q5.1 (S), Q5.2 (S), Q5.3 (S), Q6.1 (S), Q6.2 (S), Q6.3 (S), Q7.1 (S), Q7.2 (S), Q7.3 (S), Q8.1 (S), Q8.2 (S), Q8.3 (S), U1.9 (OUTN), U1.17 (OUTN); also elsewhere on the board
IN_PWRGD: U1.11 (EN); also elsewhere on the board
unnamed: C1.2, R1.1, R2.1, R3.1, R4.1
unnamed: J1.12 (TRCT1), R2.2
unnamed: J1.6 (TRCT2), R1.2
unnamed: J1.1 (TRCT3), R4.2
unnamed: J1.7 (TRCT4), R3.2
unnamed: Q1.4 (G), U1.1 (TG36)
unnamed: Q2.4 (G), U1.4 (TG45)
unnamed: Q3.4 (G), U1.16 (TG12)
unnamed: Q4.4 (G), U1.5 (TG78)
unnamed: Q5.4 (G), U1.14 (BG12)
unnamed: Q6.4 (G), U1.7 (BG78)
unnamed: Q7.4 (G), U1.13 (BG36)
unnamed: Q8.4 (G), U1.8 (BG45)
PoE_Positive: C2.2, D1.1 (A1), Q1.5 (D), Q2.5 (D), Q3.5 (D), Q4.5 (D), U1.10 (~EN), U1.12 (OUTP); also elsewhere on the board
PoE_X1: J1.13 (VC12), Q3.1 (S), Q3.2 (S), Q3.3 (S), Q5.5 (D), U1.15 (IN12)
PoE_X2: J1.14 (VC36), Q1.1 (S), Q1.2 (S), Q1.3 (S), Q7.5 (D), U1.2 (IN36)
PoE_X3: J1.15 (VC45), Q2.1 (S), Q2.2 (S), Q2.3 (S), Q8.5 (D), U1.3 (IN45)
PoE_X4: J1.16 (VC78), Q4.1 (S), Q4.2 (S), Q4.3 (S), Q6.5 (D), U1.6 (IN78)

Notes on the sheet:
Data + PoE in
Data out

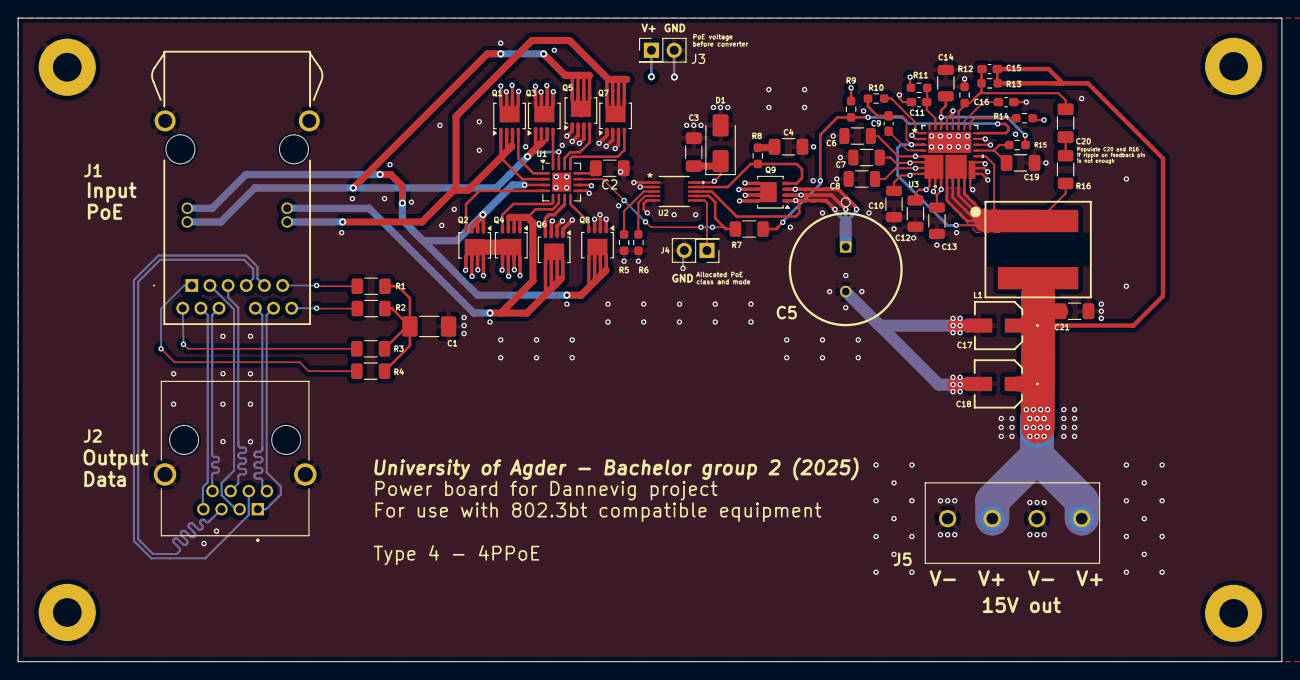
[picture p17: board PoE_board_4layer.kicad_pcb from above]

Board: 4 copper layers, 141.4 x 72.0 mm, 60 parts (0 on the bottom side), 46 nets.

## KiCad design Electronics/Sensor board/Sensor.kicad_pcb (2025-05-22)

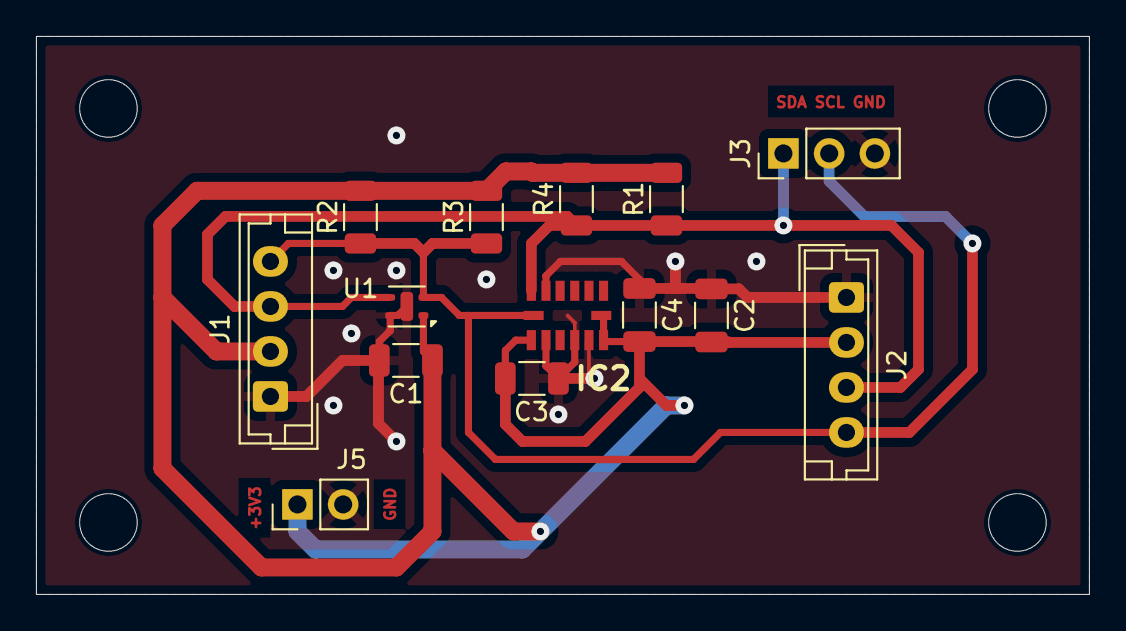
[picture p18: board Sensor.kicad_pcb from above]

Board: 2 copper layers, 58.5 x 31.0 mm, 14 parts (0 on the bottom side), 4 nets.

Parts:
C1: 100nF; C_1206_3216Metric
C2: 1uF; C_1206_3216Metric
C3: 0.1uF; C_1206_3216Metric
C4: 10uF; C_1206_3216Metric
IC2: ADXL345BCCZ; LGA14R80P3X6_300X500X100
J1, J2: Conn_01x04_Socket; JST_EH_B4B-EH-A_1x04_P2.50mm_Vertical
J3: Conn_01x03_Pin; PinHeader_1x03_P2.54mm_Vertical
J5: Conn_01x02_Pin; PinHeader_1x02_P2.54mm_Vertical
R1, R2, R3, R4: 10k; R_1206_3216Metric
U1: SHTC3; Sensirion_DFN-4-1EP_2x2mm_P1mm_EP0.7x1.6mm

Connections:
+3V3: C1.1, C2.2, C3.2, C4.2, IC2.1 (VDD_I/O), IC2.6 (VS), IC2.7 (~CS), J1.2, J2.2, J5.1, R1.2, R2.2, R3.2, R4.2, U1.1 (VDD)
GND: C1.2, C2.1, C3.1, C4.1, IC2.2 (GND_2), IC2.4 (GND_3), IC2.5 (GND), IC2.12 (SDO/ALT_ADDRESS), J1.1, J2.1, J3.3, J5.2, U1.4 (VSS), U1.5 (CP)
unnamed: IC2.14 (SCL/SCLK), J1.4, J2.4, J3.2, R2.1, R3.1, U1.2 (SCL)
unnamed: IC2.13 (SDA/SDI/SDIO), J1.3, J2.3, J3.1, R1.1, R4.1, U1.3 (SDA)

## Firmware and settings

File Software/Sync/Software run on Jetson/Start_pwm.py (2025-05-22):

import RPi.GPIO as GPIO
import time
from datetime import datetime, timedelta
from http.server import BaseHTTPRequestHandler, HTTPServer
import threading

# Setting up PWM pin
output_pins = {
    'JETSON_XAVIER': 18,
    'JETSON_NANO': 33,
    'JETSON_NX': 33,
    'CLARA_AGX_XAVIER': 18,
    'JETSON_TX2_NX': 32,
    'JETSON_ORIN': 18,
    'JETSON_ORIN_NX': 33,
    'JETSON_ORIN_NANO': 33
}
output_pin = output_pins.get(GPIO.model, None)
if output_pin is None:
    raise Exception('PWM not supported on this board')

# More accurate sleep
def sleep(duration, get_now=time.perf_counter):
    now = get_now()
    end = now + duration
    while now < end:
        now = get_now()

# Sleep until next whole second
def sleep_until_next_1sec():
    now = datetime.now()
    next_sec = (now + timedelta(seconds=1)).replace(microsecond=0)
    sleep_duration = (next_sec - now).total_seconds()
    sleep(sleep_duration)

# HTTP Server Setup
class StartRequestHandler(BaseHTTPRequestHandler):
    def do_POST(self):
        if self.path == '/start':
            print("Received /start command via HTTP. Starting PWM.")
            self.send_response(200)
            self.end_headers()
            self.server.should_start_pwm = True
        else:
            self.send_response(404)
            self.end_headers()

def run_http_server(server):
    print("HTTP server is running. Waiting for /start...")
    server.serve_forever()

def main():
    GPIO.setmode(GPIO.BOARD)
    GPIO.setup(output_pin, GPIO.OUT, initial=GPIO.HIGH)

    p = GPIO.PWM(output_pin, 60)  # 60 Hz

    # Start HTTP server in a thread
    httpd = HTTPServer(('', 8080), StartRequestHandler)
    httpd.should_start_pwm = False
    threading.Thread(target=run_http_server, args=(httpd,), daemon=True).start()

    # Wait for signal to start
    while not httpd.should_start_pwm:
        time.sleep(0.1)

    sleep_until_next_1sec()
    print("PWM synchronized every minute. Press CTRL+C to exit.")
    try:
        while True:
            sleep_until_next_1sec()
            p.start(10) # 10% duty cycle per Ser/Des datasheet
            print(f"PWM started at {datetime.now().strftime('%H:%M:%S')}")
            time.sleep(60)
            p.stop()
            print(f"PWM stopped at {datetime.now().strftime('%H:%M:%S')}")
    finally:
        GPIO.cleanup()

if __name__ == '__main__':
    main()

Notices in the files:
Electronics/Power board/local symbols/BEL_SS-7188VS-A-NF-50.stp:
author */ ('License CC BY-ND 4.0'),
